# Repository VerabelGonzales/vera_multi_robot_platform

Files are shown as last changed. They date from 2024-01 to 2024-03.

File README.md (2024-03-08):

# Plataforma Robotica Educativa Para la Implementacion de Algoritmos Relacionados a Sistemas Multi-Robot Mobiles
## Configuración del Workspace en ROS para la plataforma 
Para trabajar con la plataforma, necesitarás configurar un workspace en ROS y clonar este repositorio en tu máquina local. Sigue los pasos a continuación para configurarlo correctamente.

### Paso 1: Instalar ROS

Asegúrate de tener instalada la versión correcta de ROS en tu sistema. Para esta plataforma, se esta utilizando ROS Noetic, que es compatible con Ubuntu 20.04. Puedes encontrar las instrucciones de instalación en [ROS Wiki](http://wiki.ros.org/noetic/Installation/Ubuntu).

### Paso 2: Crear un Workspace en ROS

Abre una terminal y ejecuta los siguientes comandos para crear tu workspace de ROS:
```
    $ cd ~/catkin_ws/src
    $ cd ..
    $ catkin_make
```
### Paso 3: Configurar el Entorno ROS
Agrega el workspace a tu entorno ROS para que se cargue automáticamente cada vez que abras una terminal:
```
  echo "source ~/catkin_ws/devel/setup.bash" >> ~/.bashrc
  source ~/.bashrc
```

### Paso 4: Clonar el Repositorio
Ahora, clona este repositorio dentro del subdirectorio src de tu workspace:
```
    cd ~/catkin_ws/src
    git clone [URL_DEL_REPOSITORIO]
```
Reemplaza [URL_DEL_REPOSITORIO] con la URL de este repositorio en GitHub.

### Paso 5: Compilar el Workspace
Después de clonar el repositorio, regresa al directorio raíz de tu workspace y ejecuta catkin_make para compilar el proyecto:
```
    cd ~/catkin_ws
    catkin_make
```

### Paso 6: Listo para Trabajar
¡Ya estás listo para comenzar a trabajar con la plataforma! Asegúrate de seguir cualquier instrucción adicional específica del repositorio para ejecutar o desarrollar el proyecto.
## Diseño y Partes del Robot Omnidireccional 
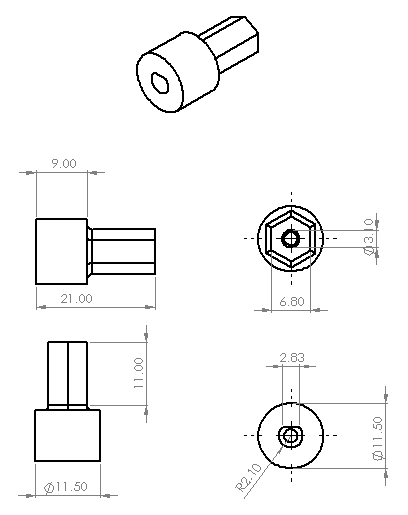
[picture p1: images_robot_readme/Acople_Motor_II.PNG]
Acoples

<p style="margin-top:10px; font-size: 16px;"><strong>Figura 1.</strong> Acoples</p>
<br>

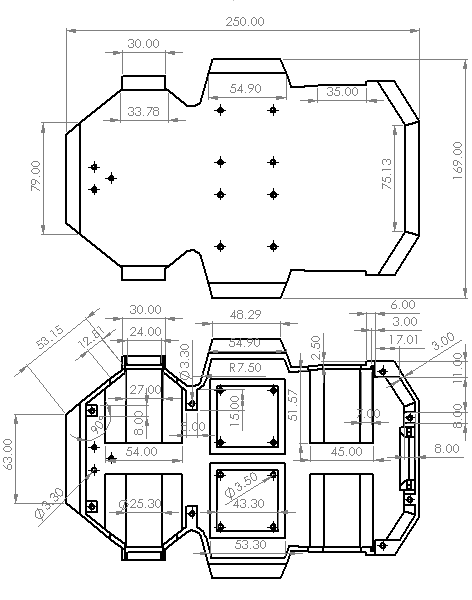
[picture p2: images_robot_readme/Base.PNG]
Base, vista superior

<p style="margin-top:10px; font-size: 16px;"><strong>Figura 2.</strong> Base, vista superior</p>
<br>

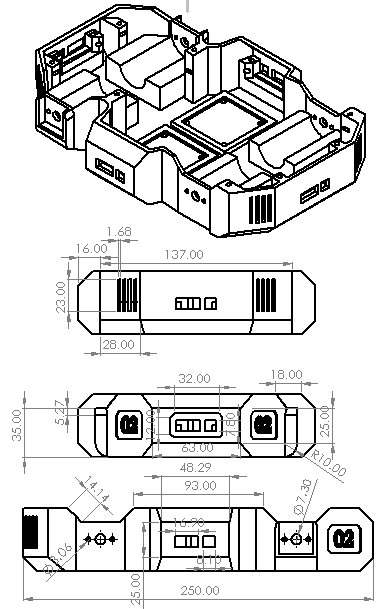
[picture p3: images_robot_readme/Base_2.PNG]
Base isométrica, vista frontal, lateral

<p style="margin-top:10px; font-size: 16px;"><strong>Figura 3.</strong> Base isométrica, vista frontal, lateral</p>
<br>

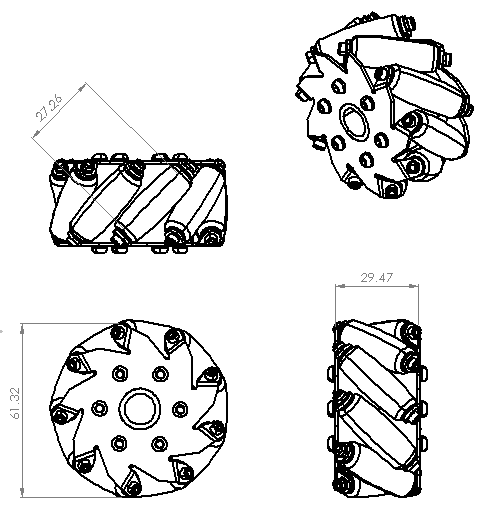
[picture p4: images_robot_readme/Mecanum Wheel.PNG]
Ruedas mecanum

<p style="margin-top:10px; font-size: 16px;"><strong>Figura 4.</strong> Ruedas mecanum</p>
<br>

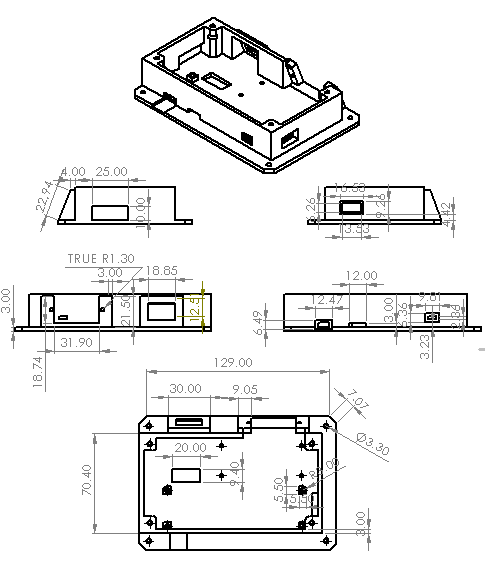
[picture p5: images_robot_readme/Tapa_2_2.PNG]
Tapa inferior del robot

<p style="margin-top:10px; font-size: 16px;"><strong>Figura 5.</strong> Tapa inferior del robot</p>
<br>

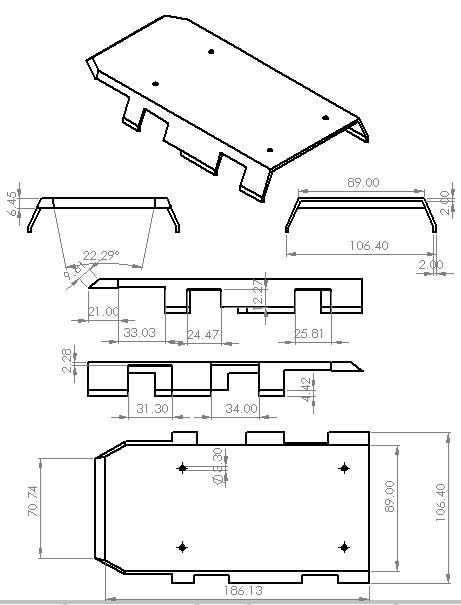
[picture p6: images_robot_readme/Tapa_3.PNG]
Tapa superior del robot

<p style="margin-top:10px; font-size: 16px;"><strong>Figura 6.</strong> Tapa superior del robot</p>
<br>

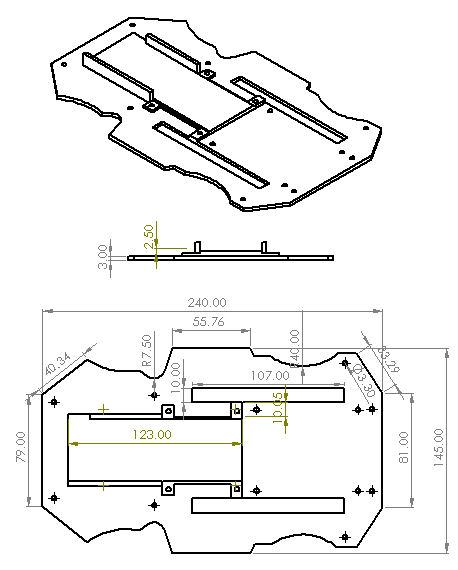
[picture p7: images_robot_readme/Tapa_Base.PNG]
Tapa base del robot

<p style="margin-top:10px; font-size: 16px;"><strong>Figura 7.</strong> Tapa base del robot</p>
<br>

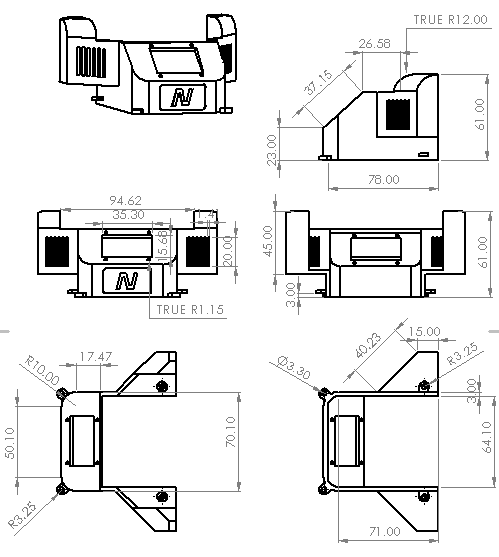
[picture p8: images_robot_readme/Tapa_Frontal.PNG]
Tapa frontal del robot

<p style="margin-top:10px; font-size: 16px;"><strong>Figura 8.</strong> Tapa frontal del robot</p>
<br>

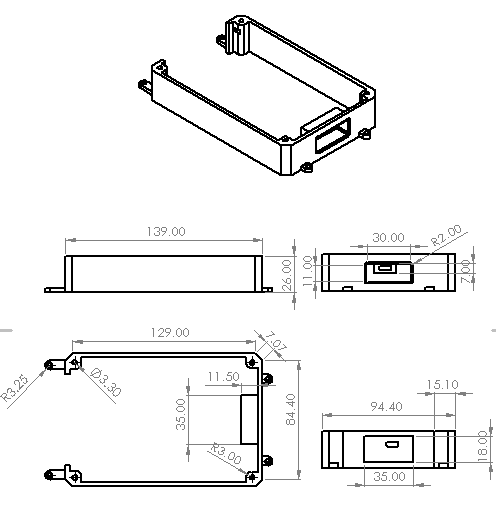
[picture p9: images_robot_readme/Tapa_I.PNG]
Tapa lateral del robot

<p style="margin-top:10px; font-size: 16px;"><strong>Figura 9.</strong> Tapa lateral del robot</p>
<br>

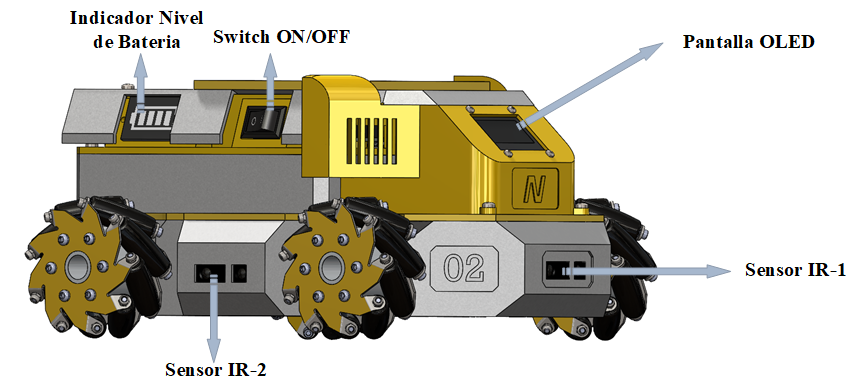
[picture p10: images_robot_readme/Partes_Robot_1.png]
Tapa frontal del robot

<p style="margin-top:10px; font-size: 16px;"><strong>Figura 10.</strong> Vista Isométrica del robot</p>
<br>

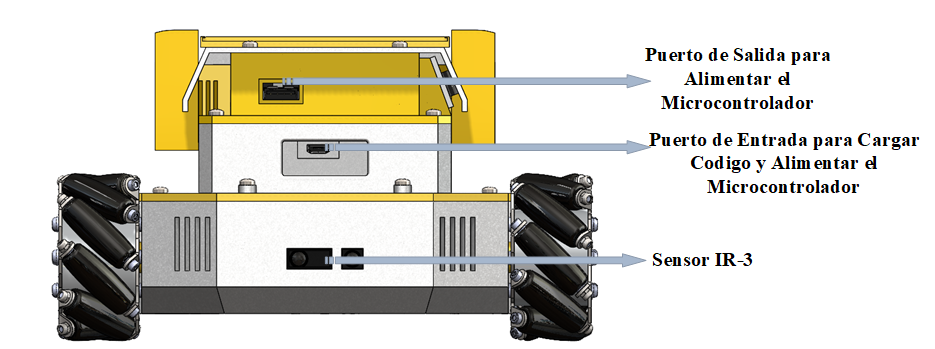
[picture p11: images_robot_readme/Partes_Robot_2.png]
Tapa frontal del robot

<p style="margin-top:10px; font-size: 16px;"><strong>Figura 11.</strong> Vista frontal del robot</p>
<br>

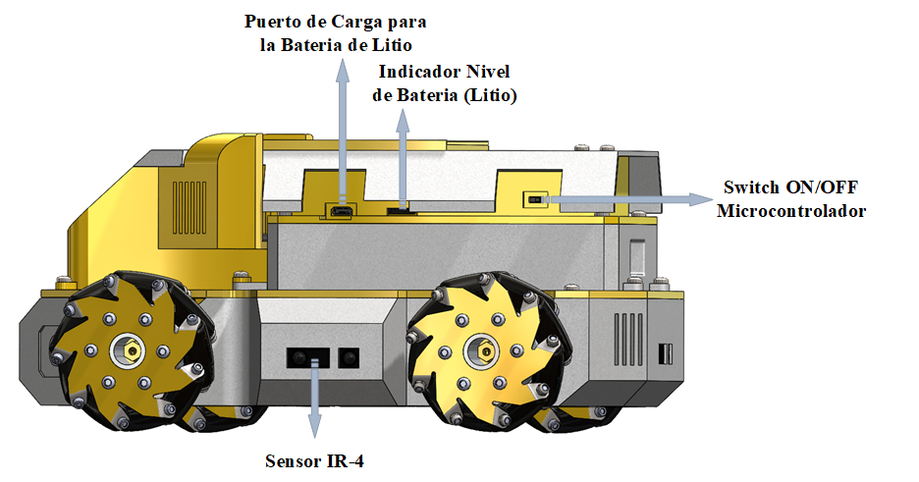
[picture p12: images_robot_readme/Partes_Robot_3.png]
Tapa frontal del robot

<p style="margin-top:10px; font-size: 16px;"><strong>Figura 12.</strong> Vista lateral del robot</p>
<br>

## Componentes que Contiene el Robot

| **Componente** | **Unidades**|
|---|---|
| Rueda Mecanum | 4 |
| Motores | 4 |
| Puente H L298N | 2 |
| Sensor IR | 4 |
| Pantalla OLED | 1 |
| Indicador Nivel de Batería| 1 |
| Regulador XL4015 | 1 |
| ESP32-WROOM 38 pines | 1 |
| Shield PCB para ESP32 | 1 |
| Shield Carga de Batería 18650 | 1 |
| Batería Lipo 3300 mAh | 1 |
| Batería Li-ion 5000 mAh | 1 |
| PCB Molex | 1 |
| Tornillos con Tuerca | 64 |
| Estructura del robot | 6 |

## Simulación Mundo Real y Mundo Simulado
### Lanzamiento de la Simulación en un Mundo Simulado con ROS y Gazebo
Para iniciar la simulación del mundo virtual con los robots, sigue estos pasos:
#### Paso 1: Lanzar la Simulación en Gazebo:
Abre una terminal y ejecuta el siguiente comando para lanzar Gazebo con el mundo simulado:
```
    roslaunch ros_world vera_robots_world_sim.launch
```
Esto abrirá Gazebo con el mundo virtual definido en el archivo vera_robots_world_sim.launch.

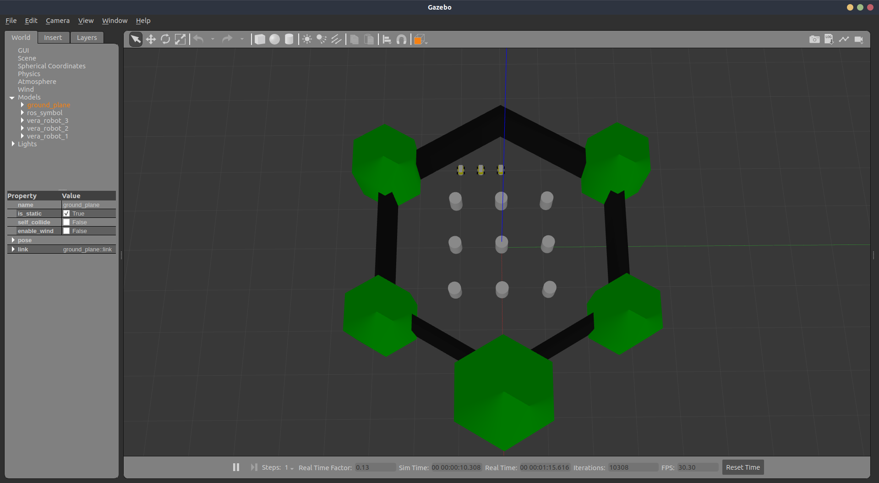
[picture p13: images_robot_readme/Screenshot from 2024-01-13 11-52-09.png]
S4

<p style="margin-top:10px; font-size: 16px;"><strong>Figura 13.</strong> Simulación gazebo mundo simulado</p>
<br>

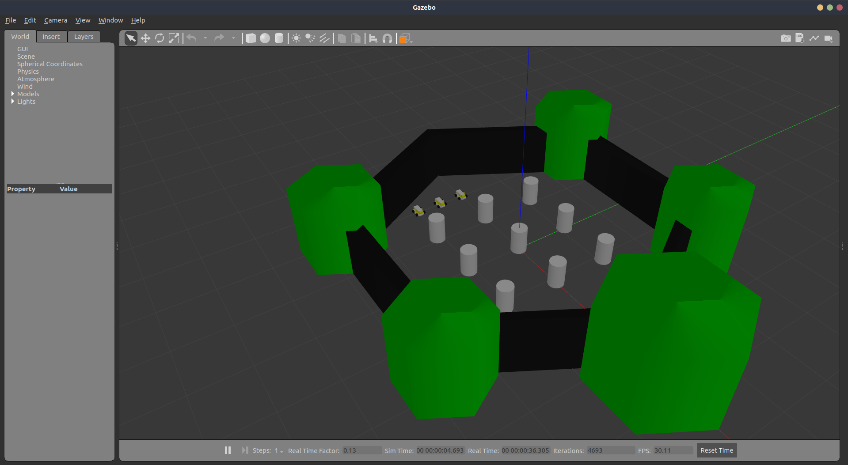
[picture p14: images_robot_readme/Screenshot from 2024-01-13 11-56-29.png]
S6

<p style="margin-top:10px; font-size: 16px;"><strong>Figura 14.</strong> Simulación gazebo mundo simulado</p>
<br>

#### Paso 2: Iniciar el Nodo de Navegación y RViz:
En una nueva terminal, ejecuta el siguiente comando para iniciar el nodo de navegación y RViz:
```
    roslaunch mrs_navigation_vera vera_robots_ros_world_sim.launch
```
Con este comando, se lanzará RViz junto con los nodos necesarios para la navegación del robot en el mundo simulado.

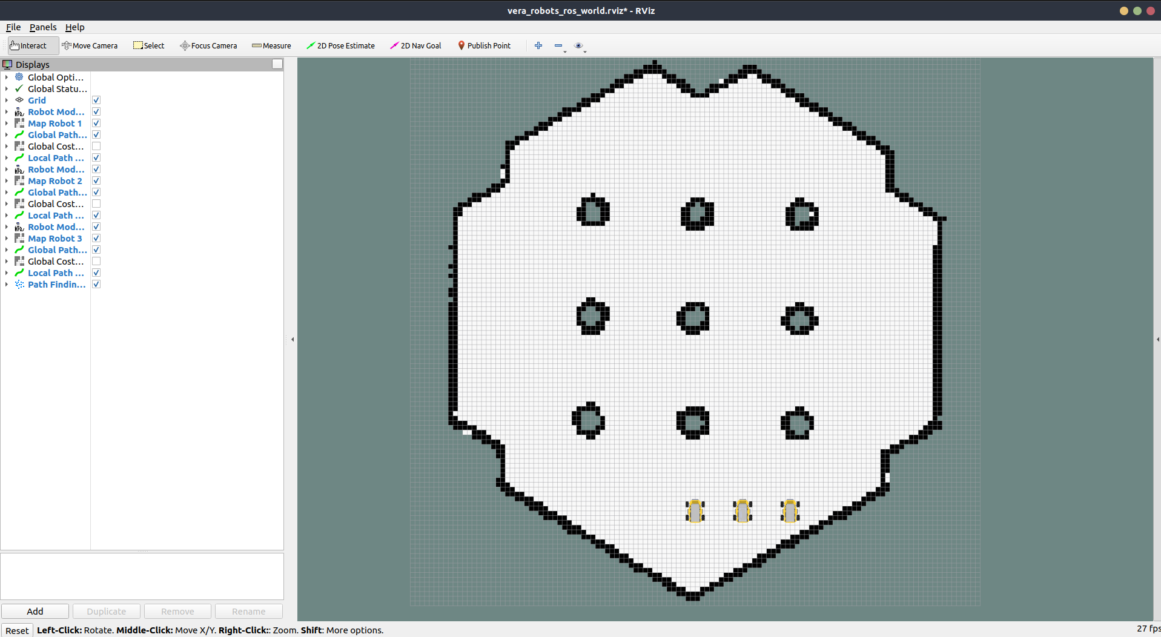
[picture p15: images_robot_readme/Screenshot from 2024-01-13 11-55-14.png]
S5

<p style="margin-top:10px; font-size: 16px;"><strong>Figura 15.</strong> Rviz mundo simulado</p>
<br>

### Lanzamiento de la Simulación en Gazebo del Mundo Real con ROS
Para ejecutar la simulación que representa un entorno del mundo real, sigue estos pasos:

#### Lanzar la Simulación del Mundo Real:
Abre una terminal y ejecuta el siguiente comando para lanzar la simulación del mundo real:
```
roslaunch mrs_navigation_vera vera_robots_ros_world_sim.launch
```
Este comando iniciará la simulación en ROS que representa un entorno del mundo real, tal como está definido en el archivo vera_robots_world_real.launch.

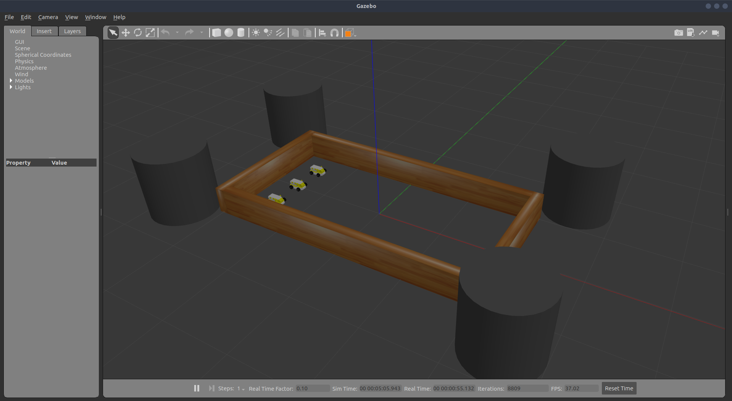
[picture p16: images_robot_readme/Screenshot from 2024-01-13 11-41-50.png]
S1

<p style="margin-top:10px; font-size: 16px;"><strong>Figura 16.</strong> Simulación Gazebo mundo real</p>
<br>

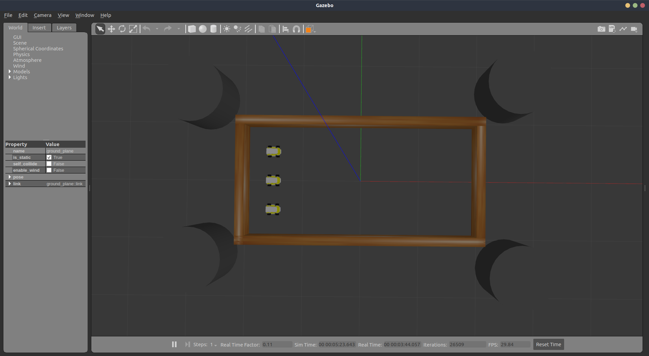
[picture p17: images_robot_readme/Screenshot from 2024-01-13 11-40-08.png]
S2

<p style="margin-top:10px; font-size: 16px;"><strong>Figura 17.</strong> Simulación Gazebo mundo real vista superior</p>
<br>

#### Iniciar el Nodo de Navegación y RViz para el Mundo Real:
En una nueva terminal, ejecuta el siguiente comando para iniciar el nodo de navegación y RViz para el entorno del mundo real:
```
    roslaunch mrs_navigation_vera vera_robots_ros_world_real.launch
```
Este comando lanzará RViz y los nodos de navegación necesarios para interactuar con el entorno simulado del mundo real.

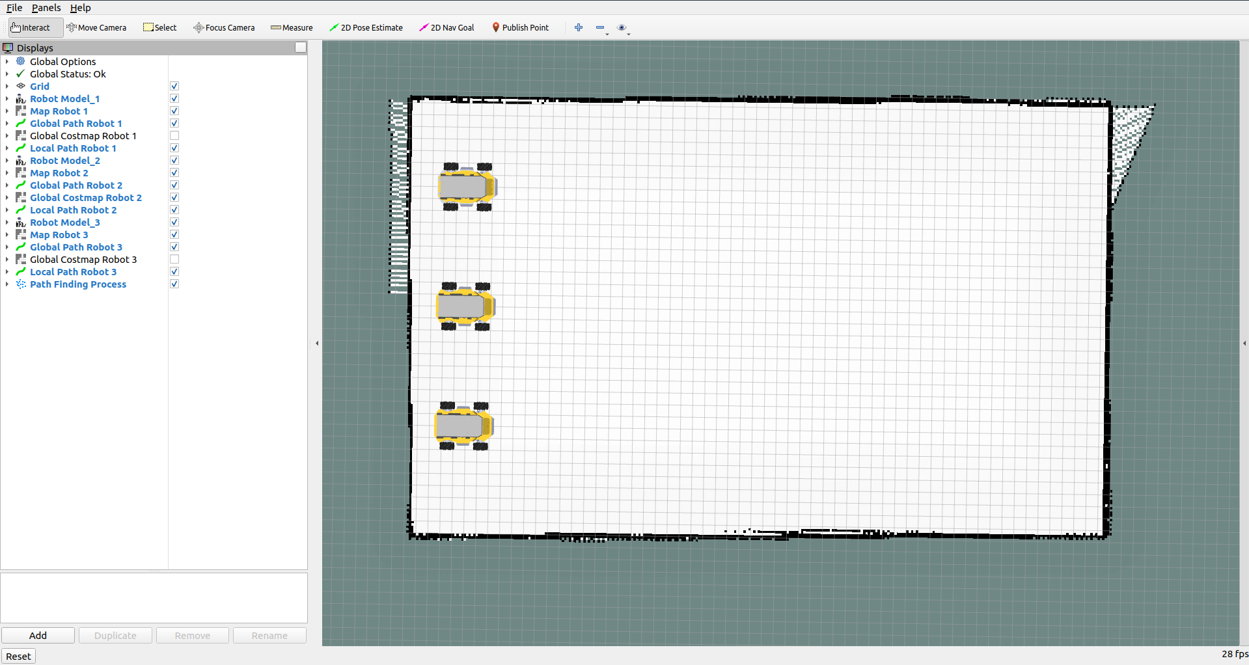
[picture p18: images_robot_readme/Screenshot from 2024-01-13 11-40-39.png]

<p style="margin-top:10px; font-size: 16px;"><strong>Figura 18.</strong> Rviz mundo real vista superior</p>
<br>

### Configuración y Lanzamiento de la Navegación Multirobot en Entornos Reales con ROS
Para configurar y ejecutar la navegación de un sistema multirobot en entornos reales, sigue estos pasos:
#### Paso 1: Iniciar Comunicación con Robots Reales
El primer paso es establecer la comunicación con los robots reales. Abre una terminal y ejecuta:
```
    roslaunch vera_mrs all_vera_robots.launch
```
Este comando inicia la comunicación serial TCP para WiFi con tres robots distintos:

* robot_1 se conecta a través del puerto TCP 11411.
* robot_2 se conecta a través del puerto TCP 11412.
* robot_3 se conecta a través del puerto TCP 11413.

#### Paso 2: Lanzar Configuración de Robots y Estimación de Pose
A continuación, lanza la configuración de los robots y la estimación de pose. En una nueva terminal, ejecuta:
```
    roslaunch vera_mrs all_vera_robots_tf_pose.launch
```
Este archivo de lanzamiento realiza lo siguiente:

* Carga las descripciones URDF de cada robot desde archivos 
  vera_robot_x.urdf.xacro.
* Ejecuta un nodo de pose_estimation.py que podría estar relacionado con la estimación de la pose de los robots o de algún objeto en el entorno.
* Inicia nodos robot_state_publisher y joint_state_publisher para cada robot, permitiendo la publicación de su estado y la manipulación de sus articulaciones.

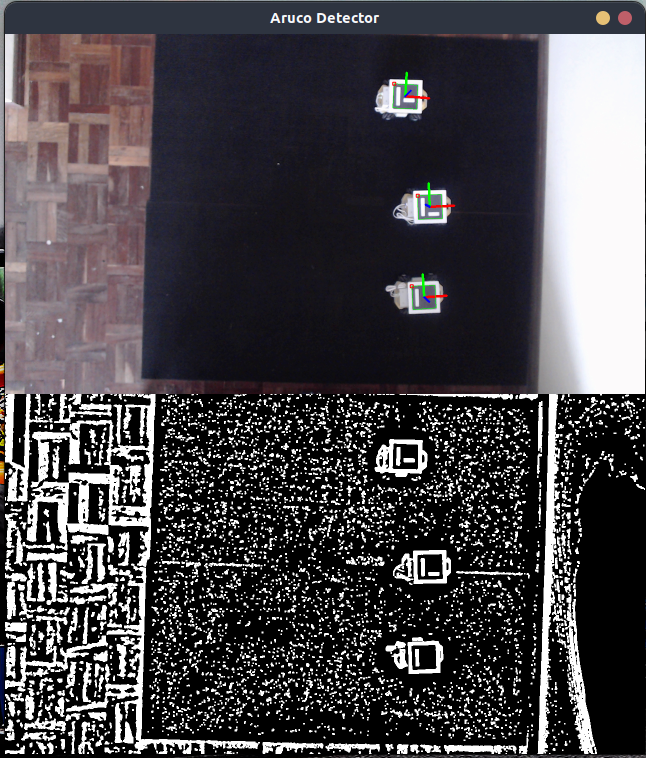
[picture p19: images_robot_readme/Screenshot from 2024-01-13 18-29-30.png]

<p style="margin-top:10px; font-size: 16px;"><strong>Figura 19.</strong> Espacio real de trabajo de la plataforma</p>
<br>

#### Paso 3: Lanzar Navegación del Sistema Multirobot
Finalmente, para iniciar la navegación del sistema multirobot, ejecuta:
```
    roslaunch mrs_navigation_vera vera_robots_ros_world_real.launch
```

Este comando configura y lanza varios componentes clave para la navegación multirobot:

* Abre RViz si está configurado (open_rviz en true), utilizando la configuración especificada en vera_robots_ros_world.rviz.
* Inicia servidores de mapas para cada robot y configura transformaciones estáticas entre los marcos de referencia del mapa y el odómetro.
* Lanza la configuración de move_base para cada robot, incluyendo la configuración de los costmaps y el planificador local, permitiendo a cada robot planificar y ejecutar trayectorias en el entorno.

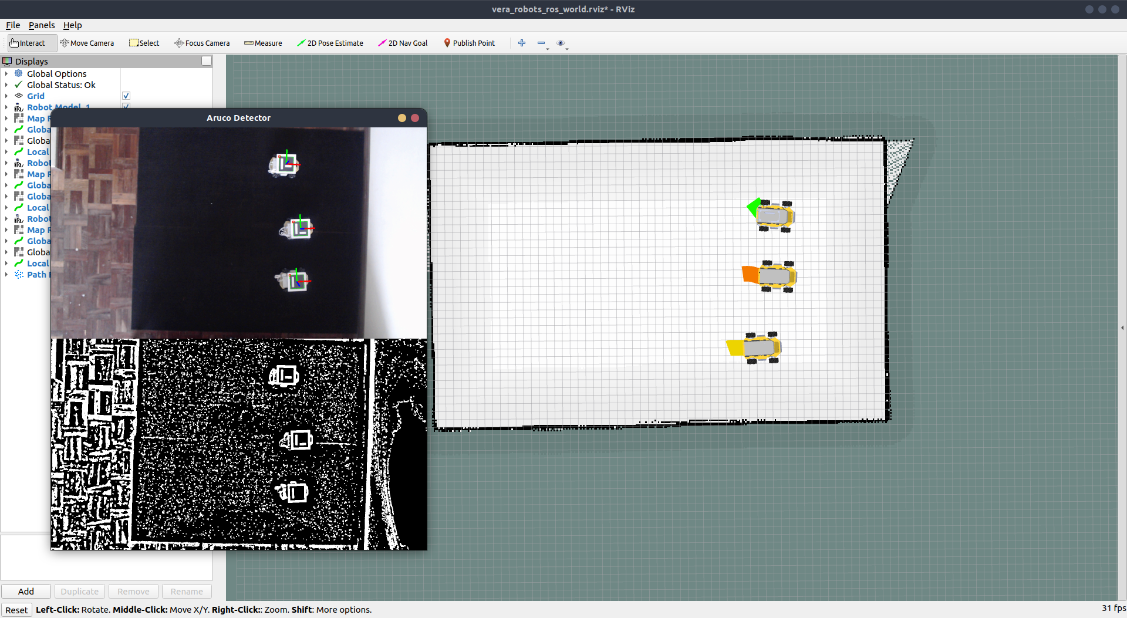
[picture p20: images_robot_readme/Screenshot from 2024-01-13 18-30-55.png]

<p style="margin-top:10px; font-size: 16px;"><strong>Figura 20.</strong> Rviz mundo real de la plataforma</p>
<br>

## Ejercicios Nivel 1
## Ejercicios Nivel 2
### Coordinación Multi-Robot: Formación en Línea Diagonal con Tres Robots Omnidireccionales (Click en el video)
En el ejercicio, se observa la descripción de una trayectoria diagonal realizada por tres robots. Esta línea diagonal se mantiene constante mientras los robots avanzan a lo largo de su recorrido hasta alcanzar el final de su trayectoria. En este ejercicio se puede ver el seguimiento de lider atraves de la comunicación maestro-esclavo.

Ver Video (https://www.youtube.com/watch?v=ncjI9gKNrXw)
### Coordinación Multi-Robot: Formación en Línea con Tres Robots Omnidireccionales (Click en el video)
En el ejercicio, se observa la descripción de una trayectoria de linea vertical realizada por tres robots. Esta línea vertical se mantiene constante mientras los robots avanzan a lo largo de su recorrido hasta alcanzar el final de su trayectoria. En este ejercicio se puede ver el seguimiento de lider atraves de la comunicación maestro-esclavo.

Ver Video (https://www.youtube.com/watch?v=EinKM8R_A2A)
### Coordinación Multi-Robot: Formación en Triangulo con Tres Robots Omnidireccionales (Click en el video)
En el ejercicio, se observa la formación de un triángulo realizada por tres robots. En este ejercicio se puede ver el seguimiento de lider atraves de la comunicación maestro-esclavo.

Ver Video (https://www.youtube.com/watch?v=X3KD1b3r-Cs)
## Ejercicios Nivel 3
### Comunicación Multi-Robot: Tres Robots Omnidireccionales Coordinados para Mover un Objeto (Click en el video)
Este ejercicio demuestra la interacción coordinada entre tres robots para desplazar un objeto. Inicialmente, un robot intenta mover el objeto por sí solo. En caso de no lograrlo, retrocede para buscar la ayuda de un segundo robot. Si ambos, trabajando en conjunto, aún no consiguen desplazar el objeto, retroceden para incorporar a un tercer robot. Finalmente, con la fuerza combinada de los tres, logran mover exitosamente el objeto.

Ver Video (https://www.youtube.com/watch?v=sbU5sWQUMAk&t=1s)
### Colaboración Multi-Robot: Tres Robots Omnidireccionales Trabajando Juntos para Desplazar un Objeto (Click en el video)
Este ejercicio ilustra la colaboración efectiva de tres robots para desplazar un objeto en línea recta, asegurando que no se produzcan desviaciones. Inicialmente, se observa el desplazamiento del objeto a lo largo del eje 'x'. A continuación, el movimiento se dirige por el eje 'y', seguido de otro desplazamiento a lo largo del eje 'x'. Finalmente, el objeto se mueve una vez más en el eje 'y'. Este patrón demuestra la precisión y la coordinación en el trabajo conjunto de los robots.

Ver Video (https://www.youtube.com/watch?v=lTV28RFhZQM)

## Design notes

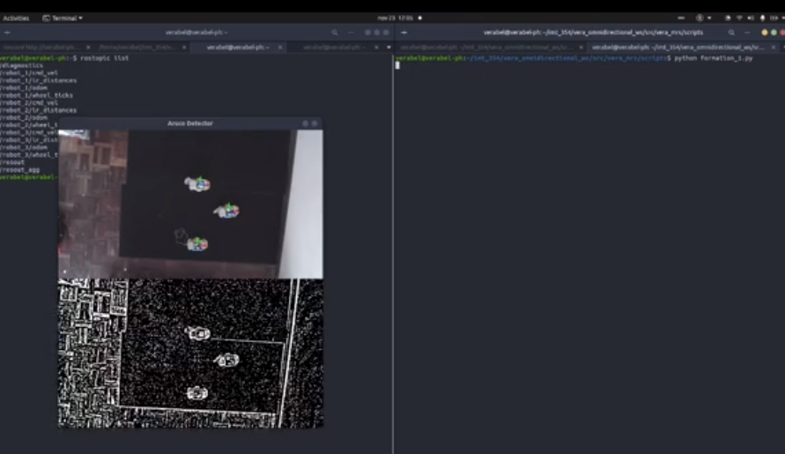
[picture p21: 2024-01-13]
images_robot_readme/triangulo_tiktok.png

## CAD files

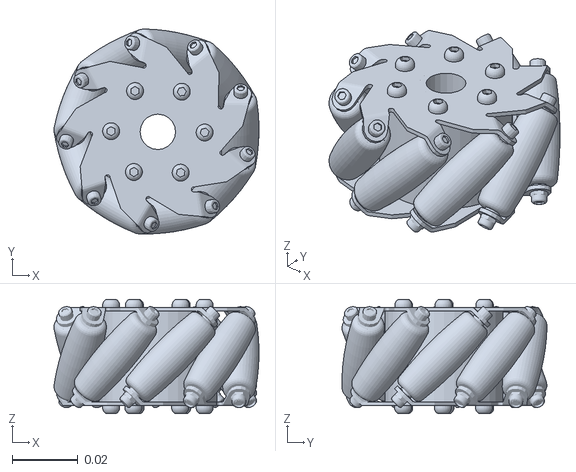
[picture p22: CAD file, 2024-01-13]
vera_mrs/meshes/vera_real/wheel_3_link.STL
0.0625 x 0.0625 x 0.0348

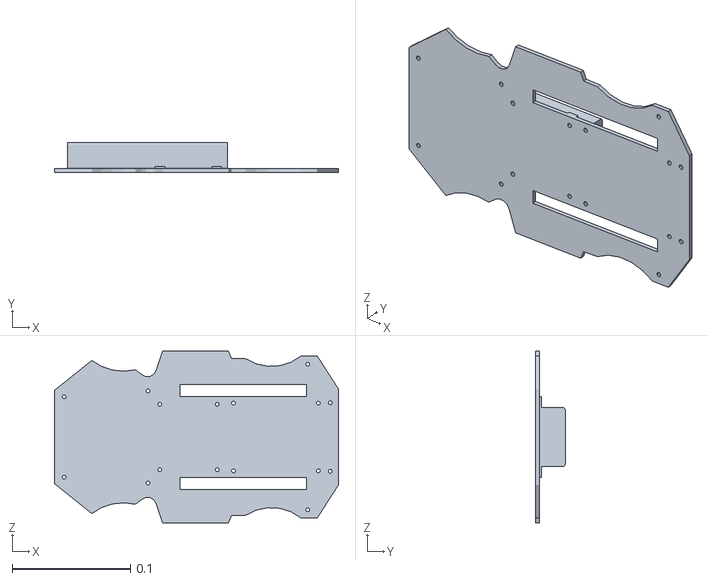
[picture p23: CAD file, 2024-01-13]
vera_mrs/meshes/vera_real/tapa_base_link.STL
0.24 x 0.025 x 0.145

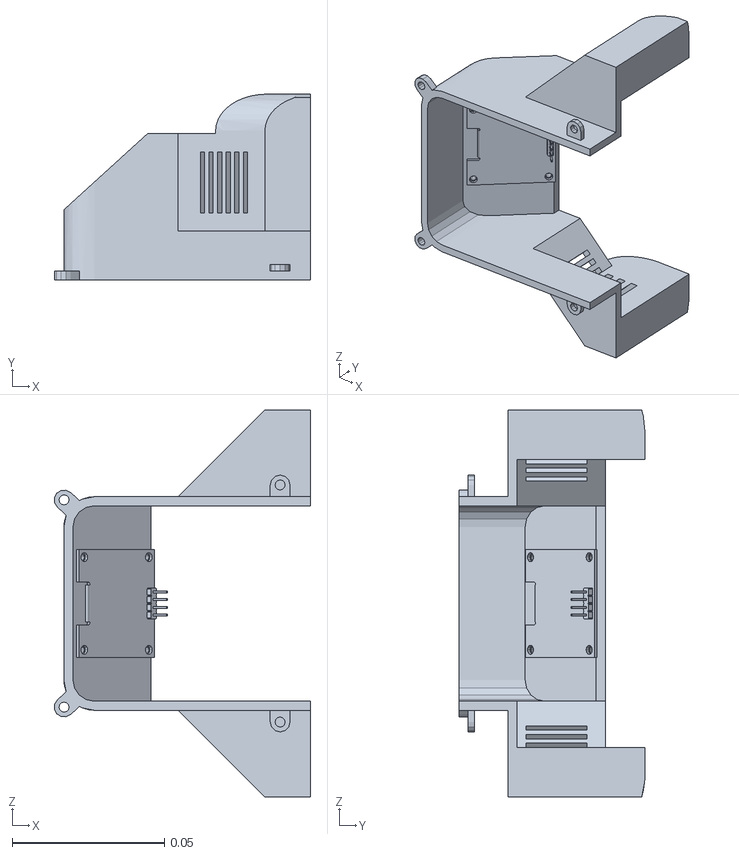
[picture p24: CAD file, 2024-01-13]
vera_mrs/meshes/vera_real/tapa_frontal_link.STL
0.0841 x 0.061 x 0.127

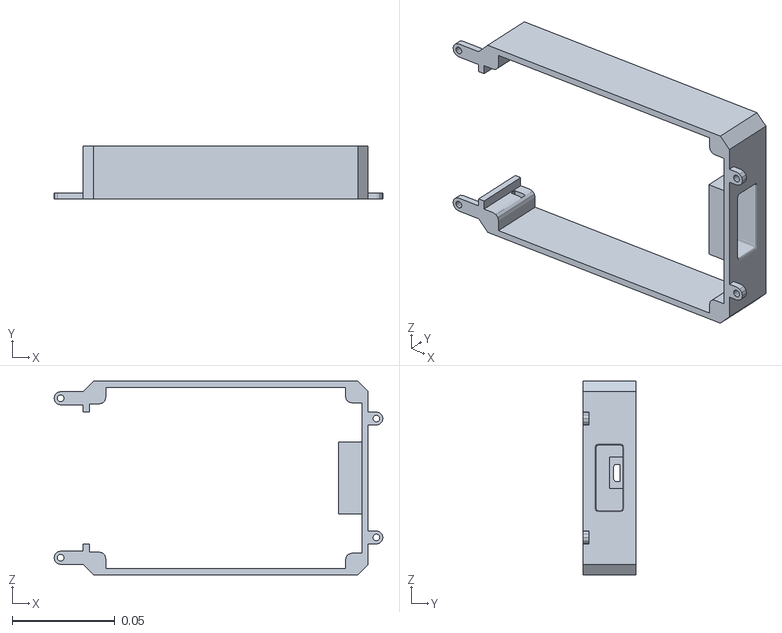
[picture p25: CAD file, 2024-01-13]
vera_mrs/meshes/vera_real/tapa_1_link.STL
0.161 x 0.026 x 0.0944

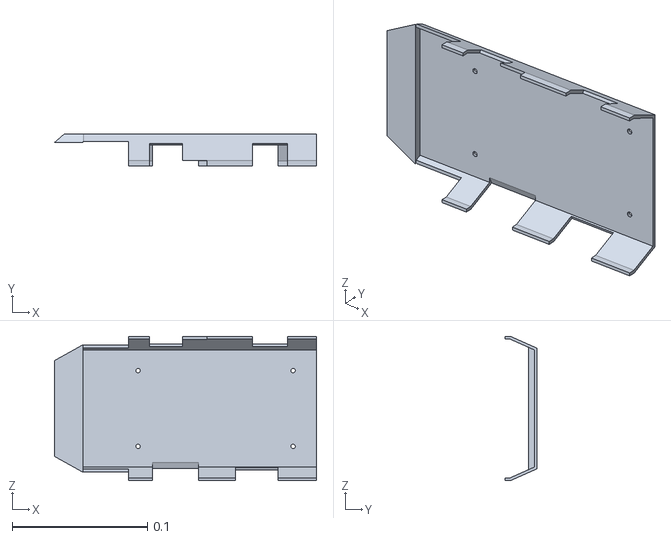
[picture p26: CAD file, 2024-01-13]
vera_mrs/meshes/vera_real/tapa_3_link.STL
0.194 x 0.024 x 0.106

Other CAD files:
vera_mrs/meshes/vera_real/wheel_4_link.STL
vera_mrs/meshes/vera_real/wheel_2_link.STL
vera_mrs/meshes/vera_real/wheel_1_link.STL

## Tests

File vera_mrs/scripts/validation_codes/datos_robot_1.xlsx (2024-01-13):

Set point [RPM] | Velocidad motor 1 [RPM] | Velocidad motor 2 [RPM] | Velocidad motor 3 [RPM] | Velocidad motor 4 [RPM] | Tiempo [s]
0 | 0 | 0 | 0 | 0 | 0.04032468796
47.74648293 | 0 | 0 | 0 | 0 | 0.06026244164
47.74648293 | 0 | 0 | 0 | 0 | 0.08018755913
47.74648293 | 0 | 0 | 0 | 0 | 0.100228548
47.74648293 | 0 | 0 | 0 | 0 | 0.1202135086
47.74648293 | 0 | 0 | 0 | 0 | 0.1401655674
47.74648293 | 0 | 0 | 0 | 0 | 0.1603012085
47.74648293 | 0 | 0 | 0 | 0 | 0.1803088188
47.74648293 | 0 | 0 | 0 | 0 | 0.2003548145
47.74648293 | 0.6091370583 | 1.218274117 | 0.3045685291 | 8.832487106 | 0.2203557491
47.74648293 | 0.6091370583 | 1.218274117 | 0.3045685291 | 8.832487106 | 0.2403008938
47.74648293 | 0.6091370583 | 1.218274117 | 0.3045685291 | 8.832487106 | 0.2603068352
47.74648293 | 0.6091370583 | 1.218274117 | 0.3045685291 | 8.832487106 | 0.2803182602
47.74648293 | 0.6091370583 | 1.218274117 | 0.3045685291 | 8.832487106 | 0.3003096581
47.74648293 | 0.6091370583 | 1.218274117 | 0.3045685291 | 8.832487106 | 0.3203442097
47.74648293 | 4.263959408 | 17.96954346 | 0.3045685291 | 24.06091309 | 0.340321064
47.74648293 | 4.263959408 | 17.96954346 | 0.3045685291 | 24.06091309 | 0.3603489399
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

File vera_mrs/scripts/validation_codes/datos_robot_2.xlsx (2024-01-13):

Set point [RPM] | Velocidad motor 1 [RPM] | Velocidad motor 2 [RPM] | Velocidad motor 3 [RPM] | Velocidad motor 4 [RPM] | Tiempo [s]
47.10986316 | 0 | 0 | 0 | 0 | 0.04027795792
47.10986316 | 0 | 0 | 0 | 0 | 0.06032824516
47.10986316 | 0 | 0 | 0 | 0 | 0.08032417297
47.10986316 | 0 | 0 | 0 | 0 | 0.1003162861
47.10986316 | 0 | 0 | 0 | 0 | 0.1202991009
47.10986316 | 0 | 0 | 0 | 0 | 0.1402850151
47.10986316 | 0 | 0 | 0 | 0 | 0.1603021622
47.10986316 | 0 | 0 | 0 | 0 | 0.1802847385
47.10986316 | 0 | 0 | 0 | 0 | 0.2003047466
47.10986316 | 0 | 0 | 0 | 0 | 0.2202999592
47.10986316 | 2.741116762 | 6.091370583 | 0.6091370583 | 3.959390879 | 0.2402806282
47.10986316 | 2.741116762 | 6.091370583 | 0.6091370583 | 3.959390879 | 0.2603068352
47.10986316 | 2.741116762 | 6.091370583 | 0.6091370583 | 3.959390879 | 0.280356884
47.10986316 | 2.741116762 | 6.091370583 | 0.6091370583 | 3.959390879 | 0.3003242016
47.10986316 | 2.741116762 | 6.091370583 | 0.6091370583 | 3.959390879 | 0.3202314377
47.10986316 | 2.741116762 | 6.091370583 | 0.6091370583 | 3.959390879 | 0.3402745724
47.10986316 | 17.36040688 | 23.75634575 | 0.6091370583 | 19.49238586 | 0.3602781296
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

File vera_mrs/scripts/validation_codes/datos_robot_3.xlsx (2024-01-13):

Set point [RPM] | Velocidad motor 1 [RPM] | Velocidad motor 2 [RPM] | Velocidad motor 3 [RPM] | Velocidad motor 4 [RPM] | Tiempo [s]
0 | 0 | 0 | 0 | 0 | 0.0603260994
47.10986316 | 0 | 0 | 0 | 0 | 0.08025074005
47.10986316 | 0 | 0 | 0 | 0 | 0.100178957
47.10986316 | 0 | 0 | 0 | 0 | 0.1202068329
47.10986316 | 0 | 0 | 0 | 0 | 0.1401987076
47.10986316 | 0 | 0 | 0 | 0 | 0.1603322029
47.10986316 | 0 | 0 | 0 | 0 | 0.1803576946
47.10986316 | 0 | 0 | 0 | 0 | 0.2003264427
47.10986316 | 0 | 0 | 0 | 0 | 0.220323801
47.10986316 | 0 | 0 | 0 | 0 | 0.2403273582
47.10986316 | 0 | 0 | 0 | 0 | 0.2603497505
47.10986316 | 0 | 0 | 0 | 0 | 0.2803328037
47.10986316 | 0 | 0 | 0 | 0 | 0.3003261089
47.10986316 | 0 | 0 | 0 | 0 | 0.320343256
47.10986316 | 0 | 0 | 0 | 0 | 0.3402576447
47.10986316 | 5.177664757 | 6.091370583 | 0.3045685291 | 3.959390879 | 0.3603444099
47.10986316 | 5.177664757 | 6.091370583 | 0.3045685291 | 3.959390879 | 0.3803319931
47.10986316 | 5.177664757 | 6.091370583 | 0.3045685291 | 3.959390879 | 0.4003381729
47.10986316 | 5.177664757 | 6.091370583 | 0.3045685291 | 3.959390879 | 0.4203453064
47.10986316 | 5.177664757 | 6.091370583 | 0.3045685291 | 3.959390879 | 0.440325737
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

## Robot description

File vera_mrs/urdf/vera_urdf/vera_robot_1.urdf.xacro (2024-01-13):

<?xml version="1.0" ?>

<robot name="vera_robot_1" xmlns:xacro="http://ros.org/wiki/xacro">
  <xacro:include filename="$(find vera_mrs)/urdf/vera_urdf/common_properties.xacro"/>
  <xacro:include filename="$(find vera_mrs)/urdf/vera_urdf/vera_robot_1.gazebo.xacro"/>
  
  <link name="robot_1/base_footprint"/>

  <joint name="robot_1/base_joint" type="fixed">
    <parent link="robot_1/base_footprint"/>
    <child link="robot_1/base_link"/>
    <origin xyz="0.0 0.0 0.0" rpy="0 0 0"/>
  </joint>

  <link name="robot_1/base_link">
    <inertial>
      <origin xyz="-0.0017615 -2.1313E-05 0.011083" rpy="0 0 0" />
      <mass value="0.51645" />
      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
    </inertial>
    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
  </link>
  <link name="robot_1/wheel_1_link">
    <inertial>
      <origin xyz="-9.6085E-11 1.5807E-10 0.017362" rpy="0 0 0" />
      <mass value="0.057589" />
      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
    </inertial>
    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
  </link>
  <joint name="robot_1/wheel_1_joint" type="continuous">
    <origin xyz="0.07 0.1019 0.018" rpy="1.5708 0 0" />
    <parent link="robot_1/base_link" />
    <child link="robot_1/wheel_1_link" />
    <axis xyz="0 0 -1" />
    <limit effort="10" velocity="10" />
    <dynamics damping="0.1" friction="0.1" />
  </joint>
  <link name="robot_1/wheel_2_link">
    <inertial>
      <origin xyz="-9.6461E-11 1.6651E-10 0.017362" rpy="0 0 0" />
      <mass value="0.057589" />
      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
    </inertial>
    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
  </link>
  <joint name="robot_1/wheel_2_joint" type="continuous">
    <origin xyz="0.07 -0.0671 0.018" rpy="1.5708 0.058243 0" />
    <parent link="robot_1/base_link" />
    <child link="robot_1/wheel_2_link" />
    <axis xyz="0 0 -1" />
    <limit effort="10" velocity="10" />
    <dynamics damping="0.1" friction="0.1" />
  </joint>
  <link name="robot_1/wheel_3_link">
    <inertial>
      <origin xyz="-9.6085E-11 1.5807E-10 0.017362" rpy="0 0 0" />
      <mass value="0.057589" />
      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
    </inertial>
    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
  </link>
  <joint name="robot_1/wheel_3_joint" type="continuous">
    <origin xyz="-0.07 -0.0671 0.018" rpy="1.5708 0 0" />
    <parent link="robot_1/base_link" />
    <child link="robot_1/wheel_3_link" />
    <axis xyz="0 0 -1" />
    <limit effort="10" velocity="10" />
    <dynamics damping="0.1" friction="0.1" />
  </joint>
  <link name="robot_1/wheel_4_link">
    <inertial>
      <origin xyz="-9.6084E-11 1.5807E-10 0.017362" rpy="0 0 0" />
      <mass value="0.057589" />
      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
    </inertial>
    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
  </link>
  <joint name="robot_1/wheel_4_joint" type="continuous">
    <origin xyz="-0.07 0.1019 0.018" rpy="1.5708 0 0" />
    <parent link="robot_1/base_link" />
    <child link="robot_1/wheel_4_link" />
    <axis xyz="0 0 -1" />
    <limit effort="10" velocity="10" />
    <dynamics damping="0.1" friction="0.1" />
  </joint>
  <link name="robot_1/tapa_base_link">
    <inertial>
      <origin xyz="0.22728 -0.042176 -0.07022" rpy="0 0 0" />
      <mass value="0.23258" />
      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
    </inertial>
    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
  </link>
  <joint name="robot_1/tapa_base_joint" type="fixed">
    <origin xyz="0.24913 0.070235 0.090722" rpy="1.5708 0 3.1416" />
    <parent link="robot_1/base_link" />
    <child link="robot_1/tapa_base_link" />
    <axis xyz="0 0 0" />
  </joint>
  <link name="robot_1/tapa_1_link">
    <inertial>
      <origin xyz="0.30517 -0.036026 -0.070252" rpy="0 0 0" />
      <mass value="0.037121" />
      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
    </inertial>
    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
  </link>
  <joint name="robot_1/tapa_1_joint" type="fixed">
    <origin xyz="0.24913 0.070235 0.090722" rpy="1.5708 0 3.1416" />
    <parent link="robot_1/base_link" />
    <child link="robot_1/tapa_1_link" />
    <axis xyz="0 0 0" />
  </joint>
  <link name="robot_1/tapa_2_link">
    <inertial>
      <origin xyz="0.29285 -0.013048 -0.070034" rpy="0 0 0" />
      <mass value="0.11383" />
      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
    </inertial>
    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
  </link>
  <joint name="robot_1/tapa_2_joint" type="fixed">
    <origin xyz="0.24913 0.070235 0.090722" rpy="1.5708 0 3.1416" />
    <parent link="robot_1/base_link" />
    <child link="robot_1/tapa_2_link" />
    <axis xyz="0 0 0" />
  </joint>
  <link name="robot_1/tapa_3_link">
    <inertial>
      <origin xyz="0.26176 0.0024264 -0.068982" rpy="0 0 0" />
      <mass value="0.048629" />
      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
    </inertial>
    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
  </link>
  <joint name="robot_1/tapa_3_joint" type="fixed">
    <origin xyz="0.24913 0.070235 0.090722" rpy="1.5708 0 3.1416" />
    <parent link="robot_1/base_link" />
    <child link="robot_1/tapa_3_link" />
    <axis xyz="0 0 0" />
  </joint>
  <link name="robot_1/tapa_frontal_link">
    <inertial>
      <origin xyz="0.19191 -0.018938 -0.070235" rpy="0 0 0" />
      <mass value="0.059907" />
      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
    </inertial>
    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
  </link>
  <joint name="robot_1/tapa_frontal_joint" type="fixed">
    <origin xyz="0.24913 0.070235 0.090722" rpy="1.5708 0 3.1416" />
    <parent link="robot_1/base_link" />
    <child link="robot_1/tapa_frontal_link" />
    <axis xyz="0 0 0" />
  </joint>
</robot>

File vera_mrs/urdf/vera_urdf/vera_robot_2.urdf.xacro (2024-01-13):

<?xml version="1.0" ?>

<robot name="vera_robot_2" xmlns:xacro="http://ros.org/wiki/xacro">
  <xacro:include filename="$(find vera_mrs)/urdf/vera_urdf/common_properties.xacro"/>
  <xacro:include filename="$(find vera_mrs)/urdf/vera_urdf/vera_robot_2.gazebo.xacro"/>
  
  <link name="robot_2/base_footprint"/>

  <joint name="robot_2/base_joint" type="fixed">
    <parent link="robot_2/base_footprint"/>
    <child link="robot_2/base_link"/>
    <origin xyz="0.0 0.0 0.0" rpy="0 0 0"/>
  </joint>

  <link name="robot_2/base_link">
    <inertial>
      <origin xyz="-0.0017615 -2.1313E-05 0.011083" rpy="0 0 0" />
      <mass value="0.51645" />
      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
    </inertial>
    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
  </link>
  <link name="robot_2/wheel_1_link">
    <inertial>
      <origin xyz="-9.6085E-11 1.5807E-10 0.017362" rpy="0 0 0" />
      <mass value="0.057589" />
      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
    </inertial>
    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
  </link>
  <joint name="robot_2/wheel_1_joint" type="continuous">
    <origin xyz="0.07 0.1019 0.018" rpy="1.5708 0 0" />
    <parent link="robot_2/base_link" />
    <child link="robot_2/wheel_1_link" />
    <axis xyz="0 0 -1" />
    <limit effort="10" velocity="10" />
    <dynamics damping="0.1" friction="0.1" />
  </joint>
  <link name="robot_2/wheel_2_link">
    <inertial>
      <origin xyz="-9.6461E-11 1.6651E-10 0.017362" rpy="0 0 0" />
      <mass value="0.057589" />
      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
    </inertial>
    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
  </link>
  <joint name="robot_2/wheel_2_joint" type="continuous">
    <origin xyz="0.07 -0.0671 0.018" rpy="1.5708 0.058243 0" />
    <parent link="robot_2/base_link" />
    <child link="robot_2/wheel_2_link" />
    <axis xyz="0 0 -1" />
    <limit effort="10" velocity="10" />
    <dynamics damping="0.1" friction="0.1" />
  </joint>
  <link name="robot_2/wheel_3_link">
    <inertial>
      <origin xyz="-9.6085E-11 1.5807E-10 0.017362" rpy="0 0 0" />
      <mass value="0.057589" />
      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
    </inertial>
    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
  </link>
  <joint name="robot_2/wheel_3_joint" type="continuous">
    <origin xyz="-0.07 -0.0671 0.018" rpy="1.5708 0 0" />
    <parent link="robot_2/base_link" />
    <child link="robot_2/wheel_3_link" />
    <axis xyz="0 0 -1" />
    <limit effort="10" velocity="10" />
    <dynamics damping="0.1" friction="0.1" />
  </joint>
  <link name="robot_2/wheel_4_link">
    <inertial>
      <origin xyz="-9.6084E-11 1.5807E-10 0.017362" rpy="0 0 0" />
      <mass value="0.057589" />
      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
    </inertial>
    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
  </link>
  <joint name="robot_2/wheel_4_joint" type="continuous">
    <origin xyz="-0.07 0.1019 0.018" rpy="1.5708 0 0" />
    <parent link="robot_2/base_link" />
    <child link="robot_2/wheel_4_link" />
    <axis xyz="0 0 -1" />
    <limit effort="10" velocity="10" />
    <dynamics damping="0.1" friction="0.1" />
  </joint>
  <link name="robot_2/tapa_base_link">
    <inertial>
      <origin xyz="0.22728 -0.042176 -0.07022" rpy="0 0 0" />
      <mass value="0.23258" />
      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
    </inertial>
    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
  </link>
  <joint name="robot_2/tapa_base_joint" type="fixed">
    <origin xyz="0.24913 0.070235 0.090722" rpy="1.5708 0 3.1416" />
    <parent link="robot_2/base_link" />
    <child link="robot_2/tapa_base_link" />
    <axis xyz="0 0 0" />
  </joint>
  <link name="robot_2/tapa_1_link">
    <inertial>
      <origin xyz="0.30517 -0.036026 -0.070252" rpy="0 0 0" />
      <mass value="0.037121" />
      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
    </inertial>
    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
  </link>
  <joint name="robot_2/tapa_1_joint" type="fixed">
    <origin xyz="0.24913 0.070235 0.090722" rpy="1.5708 0 3.1416" />
    <parent link="robot_2/base_link" />
    <child link="robot_2/tapa_1_link" />
    <axis xyz="0 0 0" />
  </joint>
  <link name="robot_2/tapa_2_link">
    <inertial>
      <origin xyz="0.29285 -0.013048 -0.070034" rpy="0 0 0" />
      <mass value="0.11383" />
      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
    </inertial>
    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
  </link>
  <joint name="robot_2/tapa_2_joint" type="fixed">
    <origin xyz="0.24913 0.070235 0.090722" rpy="1.5708 0 3.1416" />
    <parent link="robot_2/base_link" />
    <child link="robot_2/tapa_2_link" />
    <axis xyz="0 0 0" />
  </joint>
  <link name="robot_2/tapa_3_link">
    <inertial>
      <origin xyz="0.26176 0.0024264 -0.068982" rpy="0 0 0" />
      <mass value="0.048629" />
      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
    </inertial>
    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
  </link>
  <joint name="robot_2/tapa_3_joint" type="fixed">
    <origin xyz="0.24913 0.070235 0.090722" rpy="1.5708 0 3.1416" />
    <parent link="robot_2/base_link" />
    <child link="robot_2/tapa_3_link" />
    <axis xyz="0 0 0" />
  </joint>
  <link name="robot_2/tapa_frontal_link">
    <inertial>
      <origin xyz="0.19191 -0.018938 -0.070235" rpy="0 0 0" />
      <mass value="0.059907" />
      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
    </inertial>
    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
  </link>
  <joint name="robot_2/tapa_frontal_joint" type="fixed">
    <origin xyz="0.24913 0.070235 0.090722" rpy="1.5708 0 3.1416" />
    <parent link="robot_2/base_link" />
    <child link="robot_2/tapa_frontal_link" />
    <axis xyz="0 0 0" />
  </joint>
</robot>

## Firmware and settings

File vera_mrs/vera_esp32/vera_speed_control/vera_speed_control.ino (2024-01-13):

#define ROSSERIAL_ARDUINO_TCP
#define READ_PIN(pin) ((GPIO.in >> pin) & 0x1U)

#include <Arduino.h>
#include "Motor.h"
#include "Encoder.h"
#include "IRManager.h"
#include <PID_v1.h>
#include <ros.h>
#include <ros/time.h>
#include <geometry_msgs/Twist.h>
#include <std_msgs/Int16.h>
#include <std_msgs/Float32.h>
#include <std_msgs/Float32MultiArray.h>
#include <std_msgs/Int16MultiArray.h>
#include <SH1106.h>
#include <WiFi.h>

const char* ssid = "A32D9A6";
const char* password = "dhio9090";

// Configuración OLED
#define SDA_PIN 5  
#define SCL_PIN 18

// Dirección del display, SDA, SCL
SH1106 display(0x3c, SDA_PIN, SCL_PIN);  

// Sensores IR
const int numSensors = 4;
const int sensorPins[numSensors] = {36, 39, 34, 35};
const float processVar = 1; // Varianza del proceso
const float sensorVar = 2;  // Varianza del sensor
IRManager irManager(numSensors, sensorPins, processVar, sensorVar);

// Asignacion de los pines de los motores: Configuracion
Motor motor1(5, 17, 19, 3);
Motor motor2(26, 25, 27, 1);
Motor motor3(33, 32, 23, 2);
Motor motor4(18, 16, 4, 0);

// Asignacion de los pines a los encoders 
Encoder encoder1(22, 21);
Encoder encoder2(14, 12);
Encoder encoder3(2, 13);
Encoder encoder4(0, 15);

// Variables para PWM de los motores
const int freq = 5000;
const int resolution = 8;

// Variables -> Encoder 1
volatile long encoder_value1 = 0;
uint8_t last_encoder_state1 = 0;
volatile long pulse1 = 0;

// Variables -> Encoder 2
volatile long encoder_value2 = 0;
uint8_t last_encoder_state2 = 0;
volatile long pulse2 = 0; 

// Variables -> Encoder 3
volatile long encoder_value3 = 0;
uint8_t last_encoder_state3 = 0;
volatile long pulse3 = 0; 

// Variables -> Encoder 4
volatile long encoder_value4 = 0;
uint8_t last_encoder_state4 = 0;
volatile long pulse4 = 0;

// Variables para millis 
unsigned long previous_millis = 0;
unsigned long previous_millis_ir = 0;
unsigned long previous_millis_wf = 0;
unsigned long previousCallback = 0;

// RPM
float rpm1 = 0.0;
float rpm2 = 0.0;
float rpm3 = 0.0;
float rpm4 = 0.0;

// Definición de las variables PID
double Setpoint1, Input1, Output1;
double Setpoint2, Input2, Output2;
double Setpoint3, Input3, Output3;
double Setpoint4, Input4, Output4;

// Variables Kp, Ki, Kd para los motores: 1, 2, 3, 4
const double kp_m1 = 0.52998; 
const double ki_m1 = 3.583;
const double kd_m1 = 0.0058866;

const double kp_m2 = 0.52998;
const double ki_m2 = 3.583;
const double kd_m2 = 0.0058866;

const double kp_m3 = 0.52998;
const double ki_m3 = 3.583;
const double kd_m3 = 0.0058866;

const double kp_m4 = 0.52998;
const double ki_m4 = 3.583;
const double kd_m4 = 0.0058866;

//Specify the links and initial tuning parameters
PID PID_M1(&Input1, &Output1, &Setpoint1, kp_m1, ki_m1, kd_m1, DIRECT);
PID PID_M2(&Input2, &Output2, &Setpoint2, kp_m2, ki_m2, kd_m2, DIRECT);
PID PID_M3(&Input3, &Output3, &Setpoint3, kp_m3, ki_m3, kd_m3, DIRECT);
PID PID_M4(&Input4, &Output4, &Setpoint4, kp_m4, ki_m4, kd_m4, DIRECT);

const float R = 0.03; // Radio de las ruedas en metros (ajustar según tu robot)
const float L = 0.07; // Distancia desde el centro al eje X en metros (ajustar)
const float W = 0.093; // Distancia desde el centro al eje Y en metros (ajustar)

// Variables de los Tiks de los encoders
double pos_act_left_front_m1 = 0;                    
double pos_act_right_front_m2 = 0;
double pos_act_right_rear_m3 = 0;                    
double pos_act_left_rear_m4 = 0;

// Constantes de optimización
const float RPM_CONVERSION_FACTOR = 60.0 / 893;
const float RPM_MULTIPLIER = 10 * RPM_CONVERSION_FACTOR;

// Server settings
IPAddress server(192, 168, 45, 14);
uint16_t serverPort = 11411;

// CallBack Subcriptor /cmd_vel
void cmd_velCallback( const geometry_msgs::Twist& msg);

ros::NodeHandle nh;

// ROS /cmd_vel
ros::Subscriber<geometry_msgs::Twist> sub("/cmd_vel", &cmd_velCallback);

// ROS topic de los Tiks de los encoder de los motores: 1, 2, 3, 4
std_msgs::Int16MultiArray wheels_desired_rate_msg;
ros::Publisher wheels_desired_rate_pub("wheel_ticks", &wheels_desired_rate_msg);

// ROS topic de la velocidad en RPM de los motores: 1, 2, 3, 4
// std_msgs::Float32MultiArray motor_speeds_msg;
// ros::Publisher motor_speeds_pub("motor_speeds", &motor_speeds_msg);

std_msgs::Float32 motor1_msg;
ros::Publisher motor1_pub("motor_1" , &motor1_msg);

std_msgs::Float32 motor2_msg;
ros::Publisher motor2_pub("motor_2" , &motor2_msg);

std_msgs::Float32 motor3_msg;
ros::Publisher motor3_pub("motor_3" , &motor3_msg);
 
std_msgs::Float32 motor4_msg;
ros::Publisher motor4_pub("motor_4" , &motor4_msg);


// ROS topic de la distancia en cm de los sensores IR: 1, 2, 3, 4
std_msgs::Float32MultiArray ir_distances_msg;
ros::Publisher ir_distances_pub("ir_distances", &ir_distances_msg);


void setup()
{
  // Inicializar el display OLED
  display.init();
  display.flipScreenVertically();
  display.setFont(ArialMT_Plain_10);

  // Inicializacion de la conecion Wi-Fi TCP 
  setupWiFi();
  nh.getHardware()->setConnection(server, serverPort);

  // Inicializacion del nodo. 
  nh.initNode();

  // Susbcriptores 
  nh.subscribe(sub);

  // Publicadores
  nh.advertise(wheels_desired_rate_pub);

  //nh.advertise(motor_speeds_pub);
  nh.advertise(motor1_pub);
  nh.advertise(motor2_pub);
  nh.advertise(motor3_pub);
  nh.advertise(motor4_pub);

  nh.advertise(ir_distances_pub);

  // Array para almacenar las velocidades de los motores en RPM
  wheels_desired_rate_msg.data_length = 4;
  wheels_desired_rate_msg.data = new int16_t[4];

  // Array para almacenar las velocidades de los motores en RPM
  //motor_speeds_msg.data_length = 4;
  //motor_speeds_msg.data = new float[4];

  // Array la almacenar las velocidades de los sesnores IR en cm 
  ir_distances_msg.data_length = numSensors;
  ir_distances_msg.data = new float[numSensors];

  // Inicializacion de los motores
  motor1.initMotor();
  motor2.initMotor();
  motor3.initMotor();
  motor4.initMotor();

  // Inicializacion de los encoders
  encoder1.initEncoder();
  encoder2.initEncoder();
  encoder3.initEncoder();
  encoder4.initEncoder();

  // Adjuntando interrupciones para el encoder 
  attachInterrupt(digitalPinToInterrupt(encoder1.pin_a), handle_encoder1_a, CHANGE);
  attachInterrupt(digitalPinToInterrupt(encoder1.pin_b), handle_encoder1_b, CHANGE);
  attachInterrupt(digitalPinToInterrupt(encoder2.pin_a), handle_encoder2_a, CHANGE);
  attachInterrupt(digitalPinToInterrupt(encoder2.pin_b), handle_encoder2_b, CHANGE);
  attachInterrupt(digitalPinToInterrupt(encoder3.pin_a), handle_encoder3_a, CHANGE);
  attachInterrupt(digitalPinToInterrupt(encoder3.pin_b), handle_encoder3_b, CHANGE);
  attachInterrupt(digitalPinToInterrupt(encoder4.pin_a), handle_encoder4_a, CHANGE);
  attachInterrupt(digitalPinToInterrupt(encoder4.pin_b), handle_encoder4_b, CHANGE);

  // Inicializacion de las varibales PID
  Setpoint1 = 0;
  Input1 = rpm1;
  Output1 = 0;
    
  Setpoint2 = 0;
  Input2 = rpm2;
  Output2 = 0;

  Setpoint3 = 0;
  Input3 = rpm3;
  Output3 = 0;

  Setpoint4 = 0;
  Input4 = rpm4;
  Output4 = 0;
  
  // Encendido de los controladores PID para los motores. 
  PID_M1.SetMode(AUTOMATIC);
  PID_M1.SetOutputLimits(30.0 * (255.0/500.0), 400.0 * (255.0/500.0));

  PID_M2.SetMode(AUTOMATIC);
  PID_M2.SetOutputLimits(30.0 * (255.0/500.0), 400.0 * (255.0/500.0));

  PID_M3.SetMode(AUTOMATIC);
  PID_M3.SetOutputLimits(30.0 * (255.0/500.0), 400.0 * (255.0/500.0));

  PID_M4.SetMode(AUTOMATIC);
  PID_M4.SetOutputLimits(30.0 * (255.0/500.0), 400.0 * (255.0/500.0));

  Serial.begin(115200);
}

void loop()
{
  unsigned long current_millis = millis();

  // Verificación de la conexión WiFi
  if(current_millis - previous_millis_wf >= 1000){

    previous_millis_wf = current_millis;

    if (WiFi.status() != WL_CONNECTED) {

      WiFi.begin(ssid, password);
      while (WiFi.status() != WL_CONNECTED) {
      delay(100);
      }
    }

  }

  // --------------IR Sensors-----------------

  if(current_millis - previous_millis_ir >= 200)
  {
    previous_millis_ir = current_millis;

    irManager.update();
    float* distances = irManager.getDistances();
    for (int i = 0; i < numSensors; i++) 
    {
        ir_distances_msg.data[i] = distances[i];
    }

    ir_distances_pub.publish(&ir_distances_msg);
  }

  // -------------- Motores -----------------
  
  if(current_millis - previous_millis >= 100)
  {
    previous_millis = current_millis;

    rpm1 = pulse1 * RPM_MULTIPLIER;
    rpm2 = pulse2 * RPM_MULTIPLIER;
    rpm3 = pulse3 * RPM_MULTIPLIER;
    rpm4 = pulse4 * RPM_MULTIPLIER;
    
    Input1 = rpm1;
    PID_M1.Compute();
    ledcWrite(motor1.pwm_channel, 200);
    //motor_speeds_msg.data[0] = rpm1;
    motor1_msg.data = rpm1;

    Input2 = rpm2;
    PID_M2.Compute();
    ledcWrite(motor2.pwm_channel, 200);
    //motor_speeds_msg.data[1] = rpm2;
    motor2_msg.data = rpm2;

    Input3 = rpm3;
    PID_M3.Compute();
    ledcWrite(motor3.pwm_channel, 200);
    //motor_speeds_msg.data[2] = rpm3;
    motor3_msg.data = rpm3;   

    Input4 = rpm4;
    PID_M4.Compute();
    ledcWrite(motor4.pwm_channel, 200);
    //motor_speeds_msg.data[3] = rpm4;
    motor4_msg.data = rpm4;   

    updatePositions();
    resetPulses();

    publishPos();
    motor1_pub.publish(&motor1_msg);
    motor2_pub.publish(&motor2_msg);
    motor3_pub.publish(&motor3_msg);
    motor4_pub.publish(&motor4_msg);

    nh.spinOnce();
  }
}

void setupWiFi()
{
  display.clear();
  display.drawString(15, 20, "Connecting to ROS");
  display.display();

  WiFi.begin(ssid, password);
  while (WiFi.status() != WL_CONNECTED) {
    delay(5000);
  }
  
  display.clear();
  display.drawString(0, 10, "Connected to:");
  display.drawString(0, 20, WiFi.SSID());
  display.drawString(0, 30, "IP: " + WiFi.localIP().toString());
  display.display();
  delay(2000);

  display.clear();

  // Configuración de los ojos
  int eyeWidth = 40;
  int eyeHeight = 20;
  int eyeDistance = 20;
  int eyeY = (display.getHeight() / 2) - (eyeHeight / 2); 
  int centerX = display.getWidth() / 2;

  for (int i = 0; i < eyeWidth; i++) {
    int height = eyeHeight * (1 - pow(2.0 * i / eyeWidth - 1, 2));
    int topY = eyeY + (eyeHeight - height) / 2;
    display.drawLine(centerX - eyeDistance / 2 - i, topY, centerX - eyeDistance / 2 - i, topY + height);
    display.drawLine(centerX + eyeDistance / 2 + i, topY, centerX + eyeDistance / 2 + i, topY + height);
  }

  display.display();
}

void cmd_velCallback( const geometry_msgs::Twist& msg)
{
  unsigned long current_millis_cb = millis();
  
  if(current_millis_cb - previousCallback >= 100){
    previousCallback = current_millis_cb;

    if (msg.linear.x == 0.0 && msg.linear.y == 0.0 && msg.angular.z == 0.0) 
    {
      // Detener todos los motores
      Setpoint1 = 0;
      Setpoint2 = 0;
      Setpoint3 = 0;
      Setpoint4 = 0;

      // Asegurarse de que los PWM estén en 0
      ledcWrite(motor1.pwm_channel, 0);
      ledcWrite(motor2.pwm_channel, 0);
      ledcWrite(motor3.pwm_channel, 0);
      ledcWrite(motor4.pwm_channel, 0);

      digitalWrite(motor1.pin_a, LOW);
      digitalWrite(motor1.pin_b, LOW);

      digitalWrite(motor2.pin_a, LOW);
      digitalWrite(motor2.pin_b, LOW);

      digitalWrite(motor3.pin_a, LOW);
      digitalWrite(motor3.pin_b, LOW);

      digitalWrite(motor4.pin_a, LOW);
      digitalWrite(motor4.pin_b, LOW);
    
      return;  // Salir del callback
    }

    //
    float vx = msg.linear.x;
    float vy = msg.linear.y;
    float wz = msg.angular.z;

    // Modelo cinematico para un robot omnidireccional con ruedas mecanum
    float v1 = vx - vy - wz*(L + W);
    float v2 = vx + vy + wz*(L + W);
    float v3 = vx - vy + wz*(L + W);
    float v4 = vx + vy - wz*(L + W);

    // Convertir las velocidades a RPM
    rpm1 = linearToRPM(v1, R);
    rpm2 = linearToRPM(v2, R);
    rpm3 = linearToRPM(v3, R);
    rpm4 = linearToRPM(v4, R);

    // Establecer la dirección de cada motor
    setMotorDirection(motor1, v1);
    setMotorDirection(motor2, v2);
    setMotorDirection(motor3, v3);
    setMotorDirection(motor4, v4);

    // Valor absoluto de las RPM como setpoint para el PID
    Setpoint1 = abs(rpm1);
    Setpoint2 = abs(rpm2);
    Setpoint3 = abs(rpm3);
    Setpoint4 = abs(rpm4);
  }
}

// Funcion para convertir velocidad lineal a RPM
float linearToRPM(float v, float R)
{
  return v * 60 / (2 * PI * R);
}

//  Funcion para determinar la direccion de los motores en funciona al modelo cinematico. 
void setMotorDirection(Motor &motor, float speed) {
  if (speed > 0) {
    digitalWrite(motor.pin_a, HIGH);
    digitalWrite(motor.pin_b, LOW);
  } else {
    digitalWrite(motor.pin_a, LOW);
    digitalWrite(motor.pin_b, HIGH);
  }
}

// Funcion para publicar los Ticks de los encoders 
void publishPos() {

  wheels_desired_rate_msg.data[0] = pos_act_left_front_m1;
  wheels_desired_rate_msg.data[1] = pos_act_right_front_m2;
  wheels_desired_rate_msg.data[2] = pos_act_right_rear_m3;
  wheels_desired_rate_msg.data[3] = pos_act_left_rear_m4;

  wheels_desired_rate_pub.publish(&wheels_desired_rate_msg);
}

//Reset Pulsos
void resetPulses() {
    pulse1 = 0;
    pulse2 = 0;
    pulse3 = 0;
    pulse4 = 0;
}

// Actualizar posicion
void updatePositions() {
    pos_act_left_front_m1 = encoder_value1;
    pos_act_right_front_m2 = encoder_value2;
    pos_act_right_rear_m3 = encoder_value3;
    pos_act_left_rear_m4 = encoder_value4;
}

// Tick con preccion cuadruple de los encoders (Motor 1)

void update_encoder(volatile long &encoder_value, uint8_t &last_encoder_state, int pin_a, int pin_b, volatile long &pulse) {
  uint8_t state = 0;

  if (READ_PIN(pin_a)) bitSet(state, 0);
  if (READ_PIN(pin_b)) bitSet(state, 1);

  if (last_encoder_state == 2 && state == 0) encoder_value++;
  if (last_encoder_state == 0 && state == 1) encoder_value++;
  if (last_encoder_state == 3 && state == 2) encoder_value++;
  if (last_encoder_state == 1 && state == 3) encoder_value++;

  if (last_encoder_state == 1 && state == 0) encoder_value--;
  if (last_encoder_state == 3 && state == 1) encoder_value--;
  if (last_encoder_state == 0 && state == 2) encoder_value--;
  if (last_encoder_state == 2 && state == 3) encoder_value--;

  pulse++;
  last_encoder_state = state;
}
//----------------------------------------------------------------------------------------------------------------------------
void handle_encoder_a(volatile long &encoder_value, uint8_t &last_encoder_state, int pin_a, int pin_b, volatile long &pulse) {
    update_encoder(encoder_value, last_encoder_state, pin_a, pin_b, pulse);
}

void handle_encoder_b(volatile long &encoder_value, uint8_t &last_encoder_state, int pin_a, int pin_b, volatile long &pulse) {
    update_encoder(encoder_value, last_encoder_state, pin_a, pin_b, pulse);
}

//------------------------------------------------------------------------------------------------
void handle_encoder1_a() {
    handle_encoder_a(encoder_value1, last_encoder_state1, encoder1.pin_a, encoder1.pin_b, pulse1);
}

void handle_encoder1_b() {
    handle_encoder_b(encoder_value1, last_encoder_state1, encoder1.pin_a, encoder1.pin_b, pulse1);
}
//------------------------------------------------------------------------------------------------
void handle_encoder2_a() {
    handle_encoder_a(encoder_value2, last_encoder_state2, encoder2.pin_a, encoder2.pin_b, pulse2);
}

void handle_encoder2_b() {
    handle_encoder_b(encoder_value2, last_encoder_state2, encoder2.pin_a, encoder2.pin_b, pulse2);
}
//------------------------------------------------------------------------------------------------
void handle_encoder3_a() {
    handle_encoder_a(encoder_value3, last_encoder_state3, encoder3.pin_a, encoder3.pin_b, pulse3);
}

void handle_encoder3_b() {
    handle_encoder_b(encoder_value3, last_encoder_state3, encoder3.pin_a, encoder3.pin_b, pulse3);
}
//------------------------------------------------------------------------------------------------
void handle_encoder4_a() {
    handle_encoder_a(encoder_value4, last_encoder_state4, encoder4.pin_a, encoder4.pin_b, pulse4);
}

void handle_encoder4_b() {
    handle_encoder_b(encoder_value4, last_encoder_state4, encoder4.pin_a, encoder4.pin_b, pulse4);
}

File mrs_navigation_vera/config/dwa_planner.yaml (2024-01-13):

controller_frequency: 5.0
recovery_behaviour_enabled: true

NavfnROS:
  allow_unknown: true # Specifies whether or not to allow navfn to create plans that traverse unknown space.
  default_tolerance: 0.1 # A tolerance on the goal point for the planner.

TrajectoryPlannerROS:
  # Robot Configuration Parameters
  acc_lim_x: 0.2
  acc_lim_y: 0.2
  acc_lim_theta: 0.2

  max_vel_x: 0.5
  min_vel_x: -0.5
  max_vel_y: 0.5
  min_vel_y: -0.5
  max_vel_theta: 0.5
  min_vel_theta: -0.5
  
  min_in_place_vel_theta: 0.2

  holonomic_robot: true
  escape_vel: -0.1

  # Goal Tolerance Parameters
  yaw_goal_tolerance: 0.05
  xy_goal_tolerance: 0.15
  latch_xy_goal_tolerance: false

  # Forward Simulation Parameters
  sim_time: 3.0
  sim_granularity: 0.02
  angular_sim_granularity: 0.02
  vx_samples: 6
  vtheta_samples: 20
  controller_frequency: 20.0

  # Trajectory scoring parameters
  meter_scoring: true # Whether the gdist_scale and pdist_scale parameters should assume that goal_distance and path_distance are expressed in units of meters or cells. Cells are assumed by default (false).
  occdist_scale:  0.1 #The weighting for how much the controller should attempt to avoid obstacles. default 0.01
  pdist_scale: 0.75  #     The weighting for how much the controller should stay close to the path it was given . default 0.6
  gdist_scale: 1.0 #     The weighting for how much the controller should attempt to reach its local goal, also controls speed  default 0.8

  heading_lookahead: 0.325  #How far to look ahead in meters when scoring different in-place-rotation trajectories
  heading_scoring: false  #Whether to score based on the robot's heading to the path or its distance from the path. default false
  heading_scoring_timestep: 0.8   #How far to look ahead in time in seconds along the simulated trajectory when using heading scoring (double, default: 0.8)
  dwa: true #Whether to use the Dynamic Window Approach (DWA)_ or whether to use Trajectory Rollout
  simple_attractor: false
  publish_cost_grid_pc: true  

  # Oscillation Prevention Parameters
  oscillation_reset_dist: 0.25 #How far the robot must travel in meters before oscillation flags are reset (double, default: 0.05)
  escape_reset_dist: 0.1
  escape_reset_theta: 0.1

DWAPlannerROS:
  # Robot configuration parameters  
  acc_lim_x: 2.5
  acc_lim_y: 0
  acc_lim_th: 2.2

  max_vel_x: 1.0
  min_vel_x: -0.1
  max_vel_y: 0
  min_vel_y: 0

  max_trans_vel: 0.5
  min_trans_vel: 0.1
  max_rot_vel: 1.0
  min_rot_vel: 0.2

  # Goal Tolerance Parameters
  yaw_goal_tolerance: 0.1
  xy_goal_tolerance: 0.2
  latch_xy_goal_tolerance: false

  # # Forward Simulation Parameters
  # sim_time: 2.0
  # sim_granularity: 0.025
  # vx_samples: 3
  # vy_samples: 0
  # vtheta_samples: 20
  # penalize_negative_x: true

  # # Trajectory scoring parameters
  # path_distance_bias: 32.0 # The weighting for how much the controller should stay close to the path it was given
  # goal_distance_bias: 24.0 # The weighting for how much the controller should attempt to reach its local goal, also controls speed
  # occdist_scale: 255 # The weighting for how much the controller should attempt to avoid obstacles
  # forward_point_distance: 0.325 # The distance from the center point of the robot to place an additional scoring point, in meters
  # stop_time_buffer: 0.2  # The amount of time that the robot must stThe absolute value of the veolicty at which to start scaling the robot's footprint, in m/sop before a collision in order for a trajectory to be considered valid in seconds
  # scaling_speed: 0.25 # The absolute value of the veolicty at which to start scaling the robot's footprint, in m/s
  # max_scaling_factor: 0.2 # The maximum factor to scale the robot's footprint by

  # # Oscillation Prevention Parameters
  # oscillation_reset_dist: 0.25 #How far the robot must travel in meters before oscillation flags are reset (double, default: 0.05)
